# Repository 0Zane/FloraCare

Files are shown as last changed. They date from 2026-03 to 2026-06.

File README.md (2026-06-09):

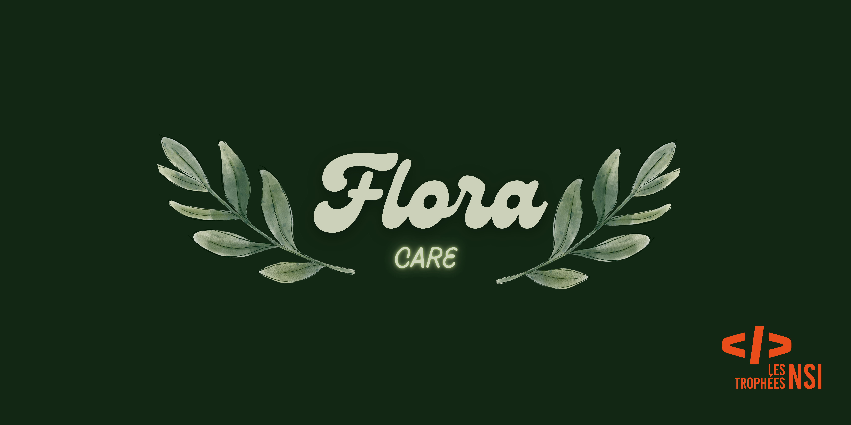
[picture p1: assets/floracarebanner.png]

# FloraCare

    

> Plant Tamagotchi — a connected device that monitors a plant's health using temperature, air humidity, soil moisture and light sensors. Built for the Trophées NSI 2026 (theme: Nature).

## 🎯 Goal

This project was created for the [Trophées NSI 2026](https://trophees-nsi.fr/) by @0Zane and @coderyansky. It offers a playful and educational experience: a digital companion that helps care for a plant by displaying real-time sensor data.

## 🏆 Awards

- **Regional Winner — Nature & Informatique**: FloraCare received the regional "Nature & Informatique" prize.
- **Nominated — Public Prize**: FloraCare was nominated for the Public Prize (see results).

See the official results: https://trophees-nsi.fr/resultats-2026

## 🧩 Hardware & Sensors

The project is based on a custom PCB driven by an **ESP32-S3**, chosen for native USB and enough power to run MicroPython.

| Component | Description | Interface / Protocol |
| :--- | :--- | :--- |
| **MCU** | ESP32-S3 Module | - |
| **PCB** | Custom design (Gerber files in `/hardware`) | - |
| **Display** | 1.9-inch 170x320 IPS color screen | **SPI** |
| **Temp / Humidity Sensor** | DHT22 | ADC |
| **Soil Moisture Sensor** | Analog soil moisture sensor | **ADC** |
| **Light Sensor** | BH1750 | **I2C** |
| **Power** | USB-C port | **5V DC -> 3.3V DC** |

> ⚡ The firmware runs on **MicroPython** and is intended to run continuously when powered via USB-C.

## 🚀 Quick Start

1. Flash MicroPython firmware to the ESP32-S3.
2. Copy all Python files to the microcontroller's flash.
3. Connect sensors to the pins defined in `main.py`.
4. Power via USB-C and observe readings on the display.

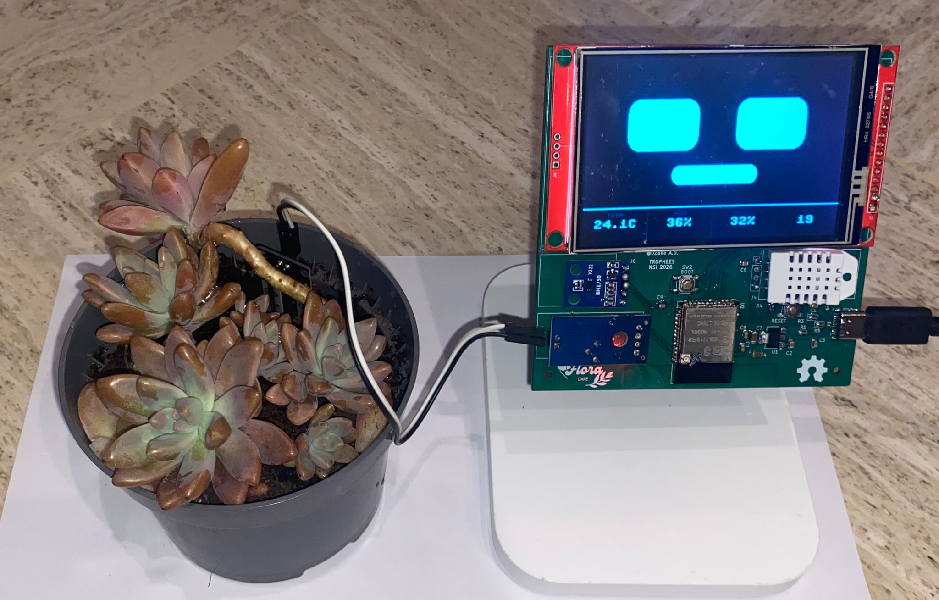
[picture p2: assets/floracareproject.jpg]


## 🌐 WiFi Web Interface

FloraCare creates a WiFi Access Point (AP) that serves a web interface to view plant data remotely.

### WiFi connection info

| Parameter | Value |
| :--- | :--- |
| **SSID** | `FloraCare` |
| **Password** | `pythonTNSI2026` |
| **IP Address** | `192.168.4.1` |
| **Protocol** | **HTTP** (port 80) |

### Accessing the web interface

1. Connect your device (phone, tablet, PC) to the `FloraCare` WiFi network.
2. Use the password `pythonTNSI2026`.
3. Open a browser and go to `http://192.168.4.1`.
4. The web page shows real-time sensor values (temperature, humidity, light, soil moisture).

> 💡 Tip: the web interface is available while the ESP32-S3 is powered via USB-C.

## 📁 Repository Structure

- `src/`: MicroPython code (main, libraries, config)
- `hardware/`: Gerber and PCB files (KiCad)
- `README.md`: project documentation and user guide
- `presentation.md`: project presentation
- `requirements.txt`: required libraries
- `LICENSE`: GPL v3

## 🤝 Contributing

This project is open source and open hardware. Contributions are welcome.
## 📝 License

This project is licensed under **GPL v3**. See the `LICENSE` file for details.

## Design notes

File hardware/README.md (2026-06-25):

# PCB FloraCare

## 📋 Description

This is the printed circuit board (PCB) for the FloraCare project, designed to control and monitor plant growing conditions.

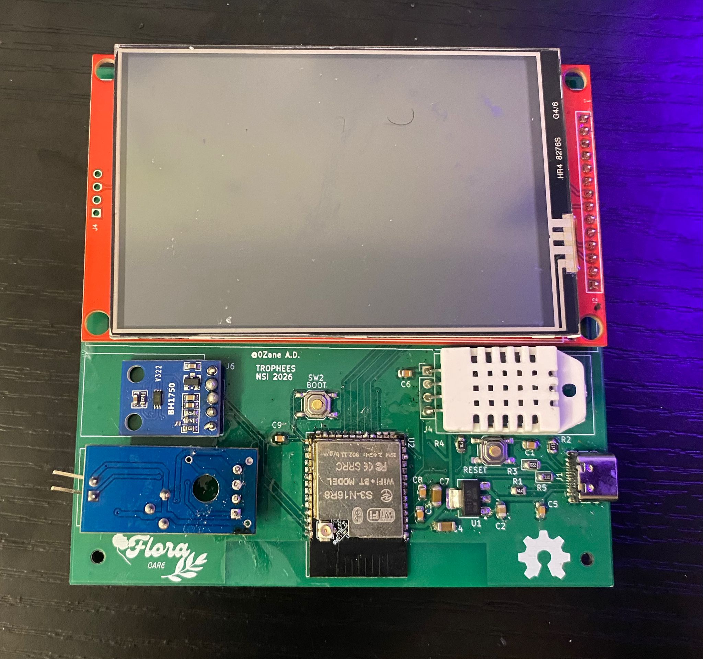
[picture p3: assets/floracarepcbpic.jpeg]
Floracare


## 🛠 Design

* **Design Tool**: KiCad
* **Design Files**:

  * `floracare.kicad_sch` - Electrical schematic
  * `floracare.kicad_pcb` - PCB layout
  * `floracare.kicad_pro` - KiCad project file

## 📐 PCB Preview

View the PCB rendering:

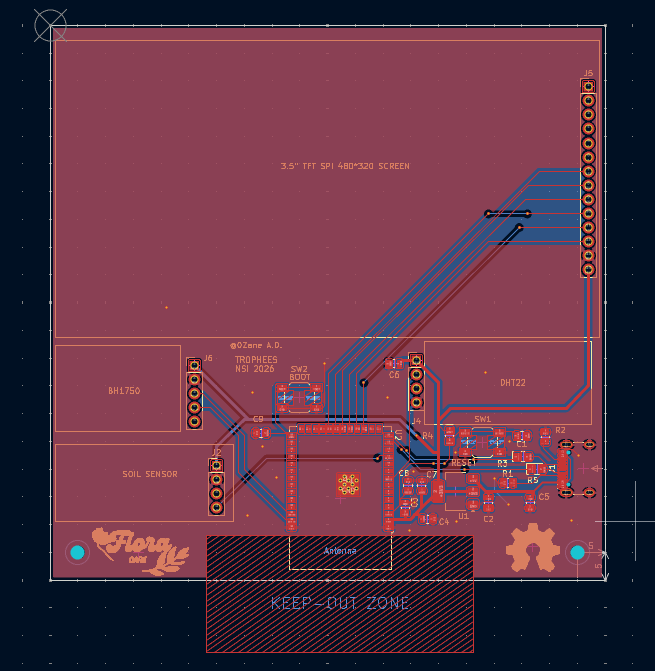
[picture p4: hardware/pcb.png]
PCB FloraCare


## 📄 Electrical Schematic

For detailed PCB documentation, see: [floracare.pdf](floracare.pdf)

## 🏭 Manufacturing

The PCB was ordered from **JLCPCB** for fabrication.
Assembly is done by hand by @0Zane.

* **Manufacturer**: JLCPCB
* **Export Format**: Gerber files + drill files

## 📦 Directory Structure

```text
hardware/
├── floracare.kicad_sch       # Electrical schematic
├── floracare.kicad_pcb       # PCB design
├── floracare.kicad_pro       # Project file
├── pcb.png                   # PCB preview
├── floracare.pdf             # Complete documentation
└── README.md                 # This file
```

## 🔧 Required Tools

To view or modify this PCB project, you will need:

* **KiCad** 9.0 (https://www.kicad.org)

---

For any questions regarding the PCB or its manufacturing process, please open a discussion in the GitHub repository's Discussions section.

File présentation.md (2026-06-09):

# 🌱 FloraCare — Project Presentation

## 1. Overall Project Overview

The project idea was born thanks to Zane, leveraging his knowledge of electronics and Python in connection with the proposed theme.

We asked ourselves the following question:  
**How can we help humans care for their plants in a playful and intuitive way?**

The objective of the *FloraCare* project is therefore to simplify understanding a plant's needs by giving it a form of "communication" with humans, through sensors and a clear interface.

---

## 2. Work Organization

### 👥 Team
- **Zane** — 1st year CS student, enthusiast of C++, Python, and electronics.
- **CoderyanskyK** — 1st year CS student, passionate about Python.

### 🛠️ Role Distribution

**Zane:**
- Python development  
- PCB design (circuit board)  
- Sensor function integration into the code  
- Wi-Fi setup and web interface via ESP  

**Coderyansky:**
- Python development  
- Sensor function integration into the code  
- Display programming (advanced graphical interface)  

### Time spent on the project:
Zane heard about the project in February and began looking for a teammate. After finding Coderyansky, we worked throughout March.

---

## 3. Project Stages

1. **Ideation and organization**
   - Team formation  
   - Reflection (~2h) on the concept and task distribution  

2. **Parallel development**
   - Zane: rapid PCB design (time constraint)  
   - CoderyanskyK: beginning screen interface development  

3. **Sensor selection (critical step)**
   - Compatibility with MicroPython  
   - Affordable cost  
   - Easy PCB integration  
   - Data relevance  

4. **Code structuring**
   - Organization for readability and performance  

5. **Advanced development**
   - Zane: Wi-Fi + web interface  
   - CoderyanskyK: screen finalization + sensors  

6. **Assembly**
   - PCB reception  
   - Soldering and hardware testing  

---

## 4. Validation and Operation

### ✅ Project Status
- Functional circuit board  
- Functional global code  

### 🧪 Testing Methods

- **Hardware tests:**
  - Use of a multimeter  
  - Verification of physical condition (temperature, circuit board robustness)

- **Software tests:**
  - Debug via console (Thonny IDE)  
  - Addition of `print` messages  

- **Data validation:**
  - Comparison with a thermometer  
  - Logical tests  
  - Real-world system usage  

### ⚠️ Challenges Encountered

- Sensor selection  
- Display programming in MicroPython  
- Setting up a Wi-Fi access point  
- Rapid PCB design (1 week)

---

## 5. Openings and Perspectives

### 🚀 Possible Improvements
- Addition of a finalized enclosure  
- Integration of more plant types  

### 🔍 Critical Analysis
The project addresses competition constraints with an original solution.  
The use of external resources (drivers, documentation) accelerated development.  
Artificial intelligence was used strategically for secondary tasks (HTML, descriptions).

### 🧠 Skills Developed
- Teamwork with GitHub  
- Rigor in electronics (no "it works roughly")  
- Application of Python skills acquired in CS in a real-world context  
- Understanding of HTTP protocol  

### 🤝 Inclusive Approach
The project aims to make plant care accessible to everyone, including beginners, through a simple and understandable interface.

---

## ⚙️ Deployment

⚠️ **Important:**  
Import **all files into flash memory** before execution (possible via ThonnyIDE).

---

## 📚 Sources

- https://docs.python.org/fr/3/howto/sockets.html  
- https://randomnerdtutorials.com/micropython-wi-fi-manager-esp32-esp8266/  
- https://requests.readthedocs.io/en/latest/  
- https://documentation.espressif.com/esp32-s3_datasheet_en.pdf
- https://github.com/lvgl-micropython/lvgl_micropython

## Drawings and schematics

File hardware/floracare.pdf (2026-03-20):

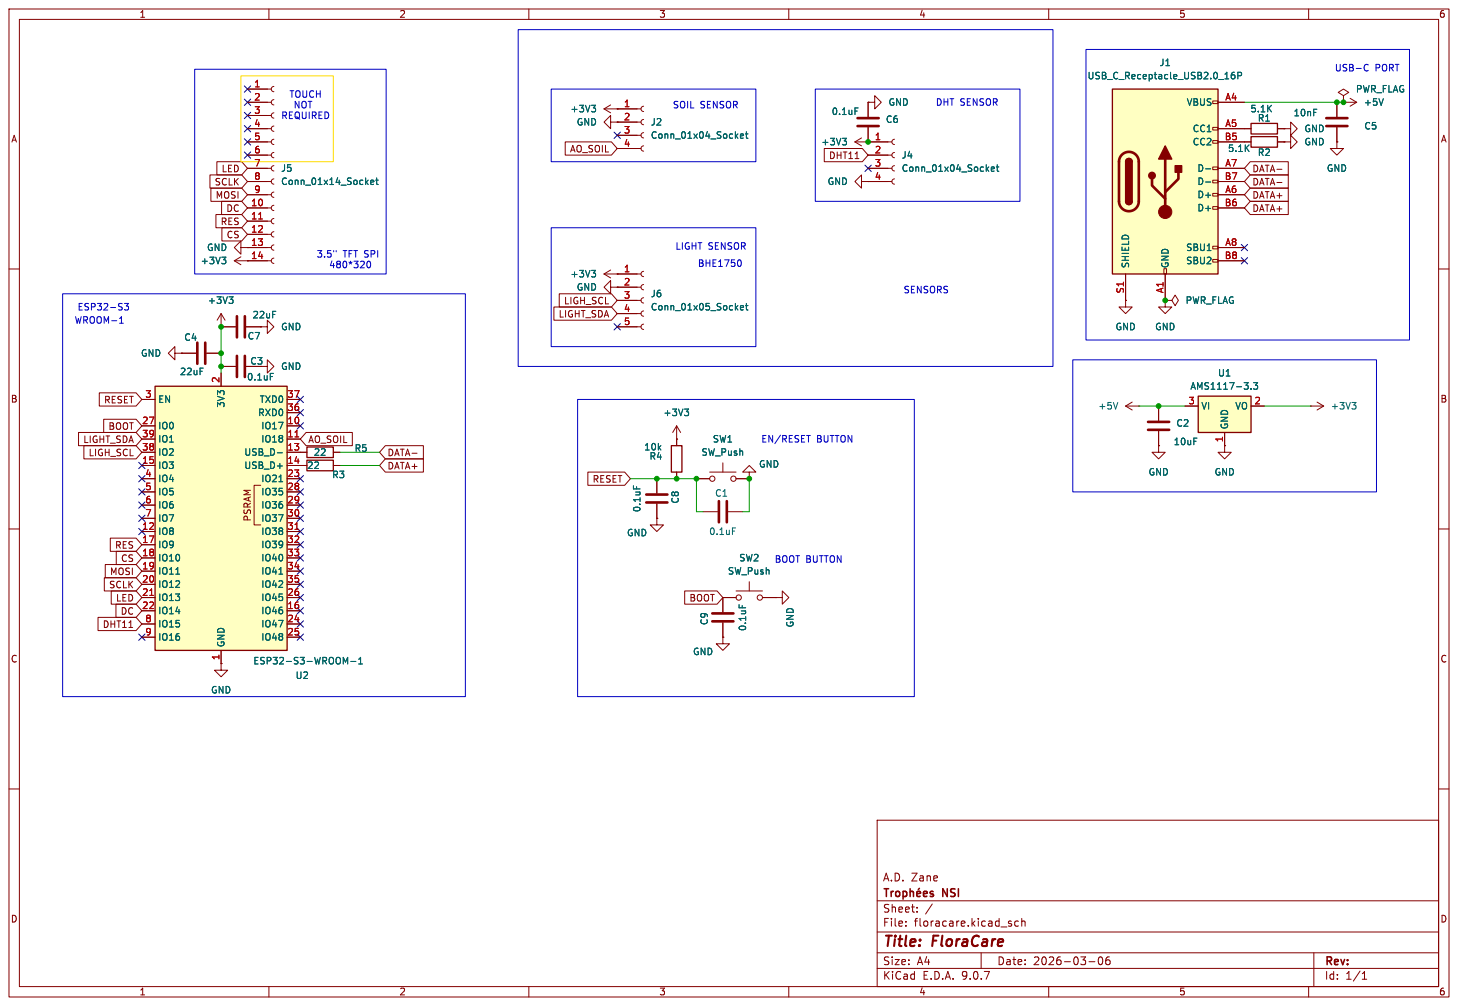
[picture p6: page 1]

+3V3 RES CS RES MOSI LED

1 VO 2 GND GND GND

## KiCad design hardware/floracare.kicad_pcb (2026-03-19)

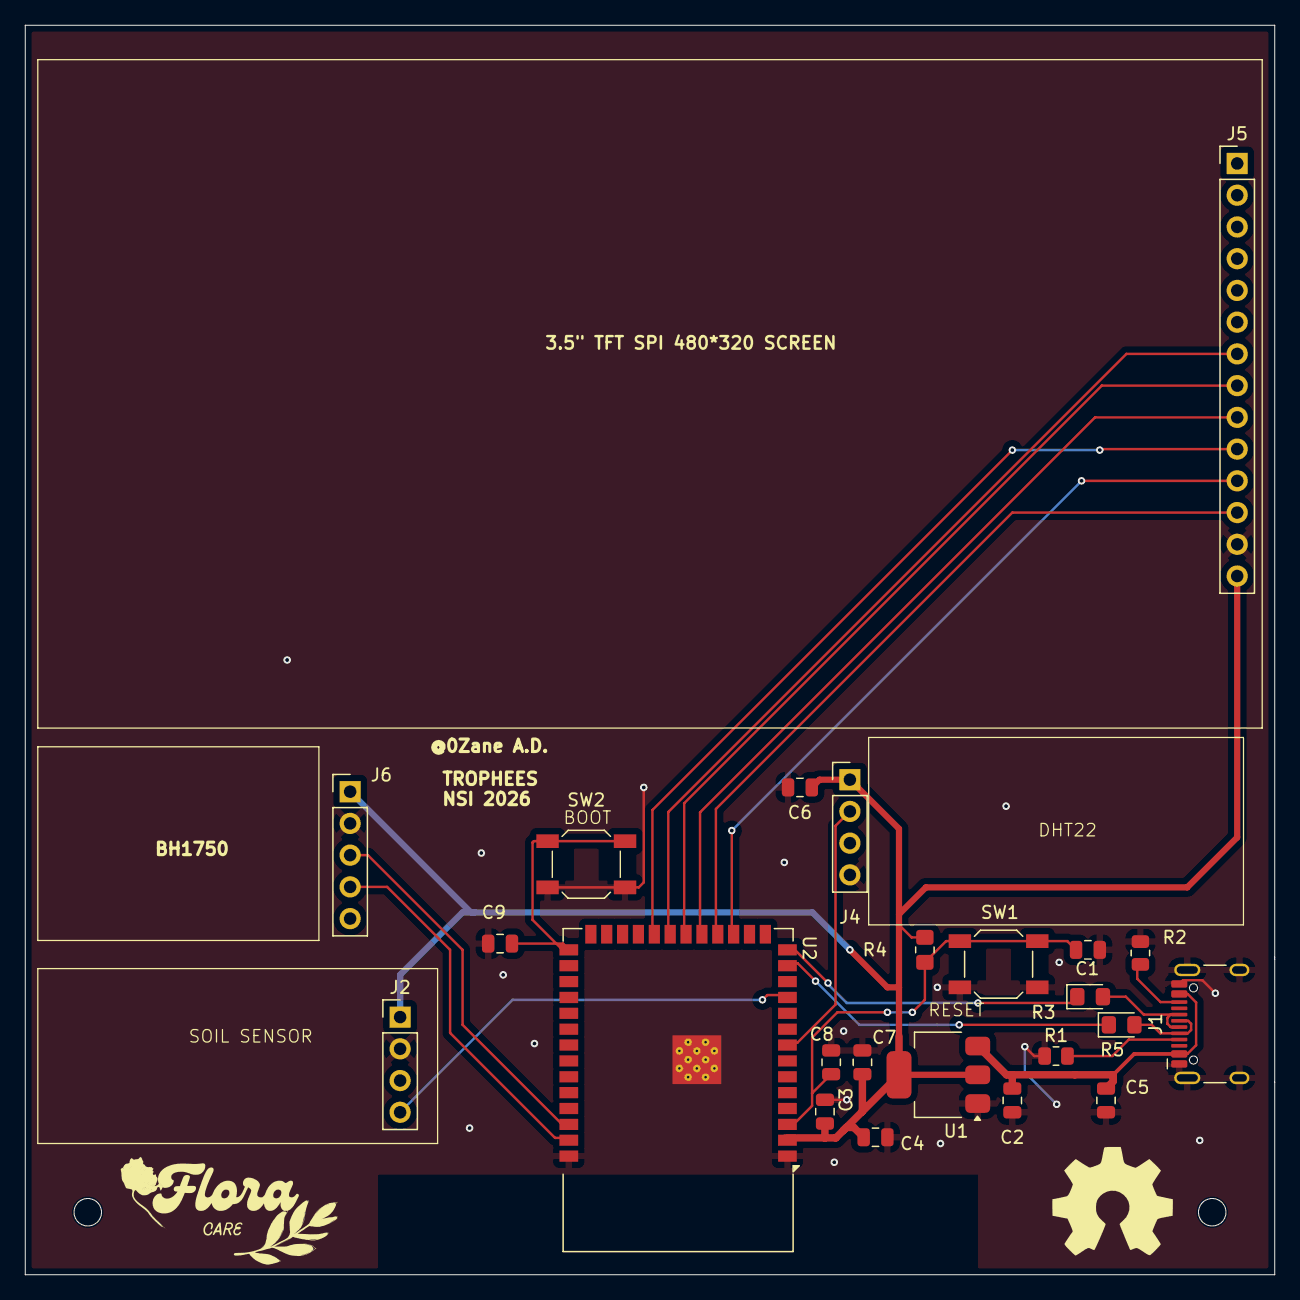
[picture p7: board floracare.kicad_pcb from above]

Board: 2 copper layers, 100.0 x 100.0 mm, 23 parts (0 on the bottom side), 21 nets.

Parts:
C1, C3, C6, C8, C9: 0.1uF; C_0805_2012Metric
C2: 10uF; C_0805_2012Metric
C4, C7: 22uF; C_0805_2012Metric
C5: 10nF; C_0805_2012Metric
J1: USB_C_Receptacle_USB2.0_16P; USB_C_Receptacle_HCTL_HC-TYPE-C-16P-01A
J2, J4: Conn_01x04_Socket; PinHeader_1x04_P2.54mm_Vertical
J5: Conn_01x14_Socket; PinHeader_1x14_P2.54mm_Vertical
J6: Conn_01x05_Socket; PinHeader_1x05_P2.54mm_Vertical
R1, R2: 5.1K; R_0805_2012Metric
R3, R5: 22; LED_0805_2012Metric_Pad1.15x1.40mm_HandSolder
R4: 10k; R_0805_2012Metric_Pad1.20x1.40mm_HandSolder
SW1, SW2: SW_Push; SW_SPST_SKQG_WithStem
U1: AMS1117-3.3; SOT-223-3_TabPin2
U2: ESP32-S3-WROOM-1

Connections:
+3V3: C3.2, C4.1, C6.1, C7.1, J2.1, J4.1, J5.14, J6.1, R4.2, U1.2 (VO), U2.2 (3V3)
+5V: C2.2, C5.1, J1.A4 (VBUS), J1.A9 (VBUS), J1.B4 (VBUS), J1.B9 (VBUS), U1.3 (VI)
AO_SOIL: J2.4, U2.11 (IO18)
BOOT: C9.2, SW2.1, U2.27 (IO0)
CS: J5.12, U2.18 (IO10)
DATA+: J1.A6 (D+), J1.B6 (D+), R3.2
DATA-: J1.A7 (D-), J1.B7 (D-), R5.2
DC: J5.10, U2.22 (IO14)
DHT11: J4.2, U2.8 (IO15)
GND: C1.2, C2.1, C3.1, C4.2, C5.2, C6.2, C7.2, C8.2, C9.1, J1.A1 (GND), J1.A12 (GND), J1.B1 (GND), J1.B12 (GND), J1.S1 (SHIELD), J2.2, J4.4, J5.13, J6.2, R1.1, R2.2, SW1.2, SW2.2, U1.1 (GND), U2.1 (GND), U2.40 (GND), U2.41 (GND)
LED: J5.7, U2.21 (IO13)
LIGHT_SDA: J6.4, U2.39 (IO1)
LIGH_SCL: J6.3, U2.38 (IO2)
MOSI: J5.9, U2.19 (IO11)
unnamed: J1.A5 (CC1), R1.2
unnamed: J1.B5 (CC2), R2.1
unnamed: R3.1, U2.14 (USB_D+)
unnamed: R5.1, U2.13 (USB_D-)
RES: J5.11, U2.17 (IO9)
RESET: C1.1, C8.1, R4.1, SW1.1, U2.3 (EN)
SCLK: J5.8, U2.20 (IO12)

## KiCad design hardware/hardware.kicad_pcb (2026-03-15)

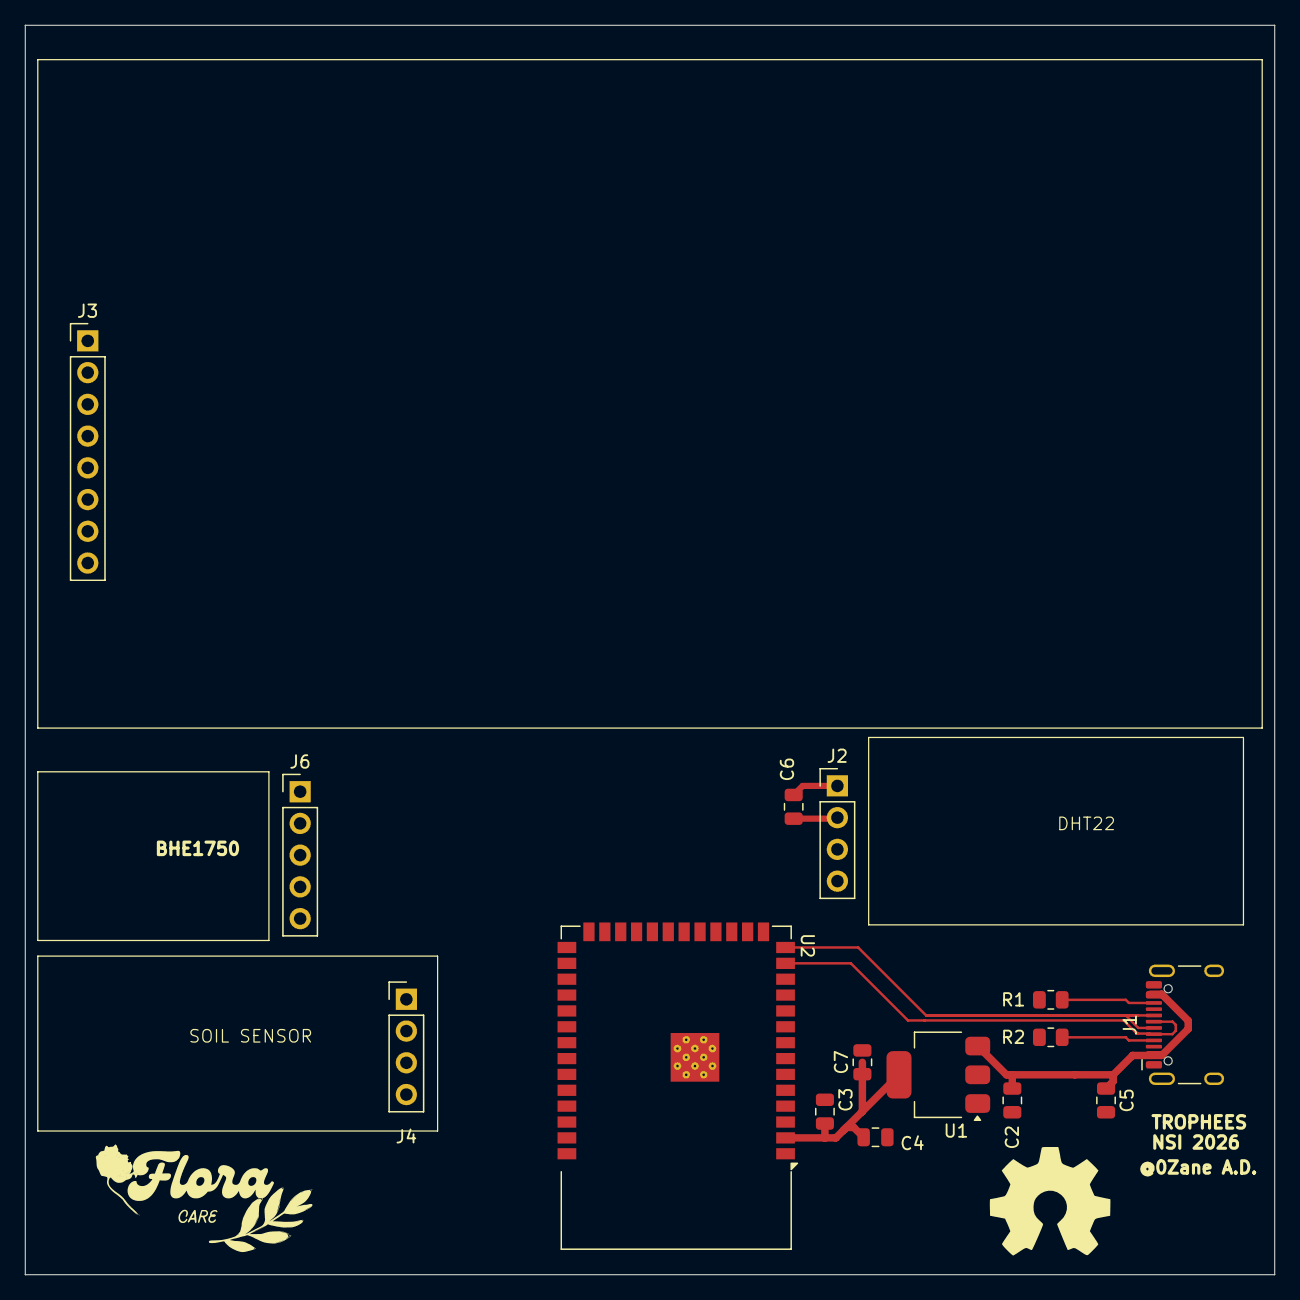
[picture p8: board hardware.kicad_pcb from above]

Board: 2 copper layers, 100.0 x 100.0 mm, 15 parts (0 on the bottom side), 14 nets.

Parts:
C2: 10uF; C_0805_2012Metric
C3, C6: 0.1uF; C_0805_2012Metric
C4, C7: 22uF; C_0805_2012Metric
C5: 10nF; C_0805_2012Metric
J1: USB_C_Receptacle_USB2.0_14P; USB_C_Receptacle_HCTL_HC-TYPE-C-16P-01A
J2, J4: Conn_01x04_Socket; PinHeader_1x04_P2.54mm_Vertical
J3: Conn_01x08_Socket; PinHeader_1x08_P2.54mm_Vertical
J6: Conn_01x05_Socket; PinHeader_1x05_P2.54mm_Vertical
R1, R2: 5.1K; R_0805_2012Metric
U1: AMS1117-3.3; SOT-223-3_TabPin2
U2: ESP32-S3-WROOM-1

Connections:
+3V3: C3.2, C4.1, C6.1, C7.1, J2.1, J3.7, J4.1, J6.1, U1.2 (VO), U2.2 (3V3)
+5V: C2.2, C5.1, J1.A4 (VBUS), J1.A9 (VBUS), J1.B4 (VBUS), J1.B9 (VBUS), U1.3 (VI)
AO_SOIL: J2.4, U2.11 (IO18)
CS: J3.2, U2.18 (IO10)
DATA+: J1.A6 (D+), J1.B6 (D+), U2.14 (USB_D+)
DATA-: J1.A7 (D-), J1.B7 (D-), U2.13 (USB_D-)
DC: J3.3, U2.22 (IO14)
DHT11: J4.2, U2.9 (IO16)
GND: C2.1, C3.1, C4.2, C5.2, C6.2, C7.2, J1.A1 (GND), J1.A12 (GND), J1.B1 (GND), J1.B12 (GND), J1.S1 (SHIELD), J2.2, J3.8, J4.4, J6.2, R1.2, R2.2, U1.1 (GND), U2.1 (GND), U2.40 (GND), U2.41 (GND)
MOSI: J3.5, U2.19 (IO11)
unnamed: J1.A5 (CC1), R2.1
unnamed: J1.B5 (CC2), R1.1
RES: J3.4, U2.21 (IO13)
SCLK: J3.6, U2.20 (IO12)

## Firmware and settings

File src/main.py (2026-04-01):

import dht
import time
from machine import Pin, ADC, I2C
import socket
import network
from webpage import webpage
import ujson
from statehandler import plantstate
from drivers.display.robot_face import Display as FaceDisplay, Face
from drivers.display.anims.idle import IdleAnim
from drivers.display.anims.angry import AngryAnim

# --- Sensor pins ---
SOIL_PIN  = 18
DHT_PIN   = 15
LIGHT_SCL = 2
LIGHT_SDA = 1

# --- Screen pins ---
RES  = 9
CS   = 10
MOSI = 11
SCLK = 12
LED  = 13
DC   = 14


# --- Hardware addresses ---
BH1750_ADDR       = 0x23
BH1750_CONT_H_RES = 0x10

# --- Wi-Fi access point ---
SSID          = "FloraCare"
WIFIPASSWORD  = "pythonTNSI2026"
MAX_USER      = 4
MAX_PACKETSIZE = 1024
APWIFI = True  # set to False when the AP is disabled at runtime

# --- Plant models ---
orchidee = {"name": "ORCHIDEE", "humid": 65, "temp": 22, "moisture": 55, "light": 45}
cactus   = {"name": "CACTUS",   "humid": 20, "temp": 28, "moisture": 20, "light": 85}
monstera = {"name": "MONSTERA", "humid": 58, "temp": 24, "moisture": 60, "light": 40}
jacinthe = {"name": "JACINTHE", "humid": 50, "temp": 14, "moisture": 50, "light": 70}
graptosedum = {"name": "GRAPTOSEDUM", "humid": 40, "temp":22, "moisture": 40, "light": 50 }

# Dictionary mapping POST plant names to their model
PLANT_MODELS = {
    "orchidee": orchidee,
    "cactus":   cactus,
    "monstera": monstera,
    "jacinthe": jacinthe,
    "graptosedum": graptosedum
}

# --- Light average state ---
period  = 0
lum_sum = 0
lightstate = 0
# --- Plant target thresholds (updated when a plant is selected via the web UI) ---
norm_air_temp = 22
norm_air_hum  = 40
norm_moisture = 50
norm_light    = 1

# --- Sensor initialisation ---
capteur = dht.DHT22(Pin(DHT_PIN))
adc     = ADC(Pin(SOIL_PIN))
i2c     = I2C(0, sda=Pin(LIGHT_SDA), scl=Pin(LIGHT_SCL), freq=400000)
try:
    i2c.writeto(BH1750_ADDR, bytes([BH1750_CONT_H_RES]))
except:
    print("Light sensor not found — skipping init")


# --- Sensor read functions ---

def read_light():
    try:
        data = i2c.readfrom(BH1750_ADDR, 2)
        return (data[0] << 8 | data[1]) / 1.2
    except:
        return -1


def read_soil():
    try:
        adc.atten(ADC.ATTN_11DB)
        raw = adc.read_u16()
        moisture_pct = max(0, min(100, 100 - (raw * 100 // 65535)))
        return raw, moisture_pct
    except:
        return -1, -1


def read_temp():
    try:
        capteur.measure()
        temp = capteur.temperature()
        humi = capteur.humidity()
        return temp, humi
    except:
        return -1, -1


# --- Wi-Fi access point ---

def launch_ap():
    try:
        sta = network.WLAN(network.AP_IF)
        sta.active(True)
        sta.config(essid=SSID, authmode=network.AUTH_WPA_WPA2_PSK, password=WIFIPASSWORD)
        print("Network config:", sta.ifconfig())
    except:
        print("Failed to launch AP")


# --- Boot sequence ---

launch_ap()

face = Face(FaceDisplay())
face.set_anim(IdleAnim())

try:
    socketFloraCare = socket.socket(socket.AF_INET, socket.SOCK_STREAM)
    socketFloraCare.setsockopt(socket.SOL_SOCKET, socket.SO_REUSEADDR, 1)
    socketFloraCare.bind(('', 80))
    socketFloraCare.listen(MAX_USER)
    socketFloraCare.setblocking(False)
    print("Server listening on port 80")
except Exception as e:
    print(f"Error creating socket: {e}")
    socketFloraCare = None

# --- Main loop ---

_sensor_at = time.ticks_ms()
_temp = _humi = _soil_pct = _lux = -1

while True:
    face.update()

    if socketFloraCare and APWIFI:
        try:
            conn, addr = socketFloraCare.accept()
            conn.settimeout(2.0)
            print("Connection from", addr)
            request    = conn.recv(MAX_PACKETSIZE).decode('utf-8')
            first_line = request.split('\r\n')[0]
            print(request)

            if "POST /save" in first_line:
                try:
                    parts = request.split('\r\n\r\n')
                    if len(parts) > 1:
                        data       = ujson.loads(parts[1])
                        plant_name = data.get("plant")
                        selected   = PLANT_MODELS.get(plant_name)

                        if selected:
                            norm_air_temp = selected["temp"]
                            norm_air_hum  = selected["humid"]
                            norm_moisture = selected["moisture"]
                            norm_light    = selected["light"]
                            print(f"Succès : {plant_name} configurée.")
                            print(f"Objectif : Temp {norm_air_temp}°C, Hum {norm_air_hum}%")
                        else:
                            print(f"Erreur : La plante '{plant_name}' n'existe pas dans la base de données FloraCare")

                        conn.send("HTTP/1.1 200 OK\r\nContent-Type: application/json\r\n\r\n")
                except Exception as e:
                    print("POST /save error:", e)

            elif "POST /wifi_off" in first_line:
                conn.send("HTTP/1.1 200 OK\r\n\r\nDisabling Wi-Fi...")
                conn.close()
                time.sleep(1)
                network.WLAN(network.AP_IF).active(False)
                APWIFI = False
                print("Wi-Fi AP disabled")

            else:
                response = webpage()
                conn.send("HTTP/1.0 200 OK\r\nContent-type: text/html\r\n\r\n")
                conn.send(response)
                conn.close()

        except:
            pass  # no incoming connection — non-blocking accept raises here

    # Read sensors every 2 s without blocking the animation loop
    if time.ticks_diff(time.ticks_ms(), _sensor_at) >= 0:
        _sensor_at = time.ticks_ms() + 2000

        try:
            _temp, _humi = read_temp()
            # DHT22 and display DC share GPIO 15 — restore pin direction after DHT use
            face.lcd.restore_dc()
            _raw, _soil_pct = read_soil()
            _lux            = read_light()

            tempstate, humstate, moiststate = plantstate(
                _temp, norm_air_temp, _humi, norm_air_hum, _soil_pct, norm_moisture
            )

            if period < 1000:
                period  += 1
                lum_sum += _lux
            elif period >= 1000:
                period  = 0
                avg_lum = lum_sum // 1000
                lum_sum = 0
                if avg_lum + 10 < norm_light:
                    lightstate = -1
                    print("Votre plante est en manque de lumière depuis quelques temps.")

            if any(s != 0 for s in (tempstate, humstate, moiststate, lightstate)):
                if not isinstance(face._anim, AngryAnim):
                    face.set_anim(AngryAnim())
            else:
                if not isinstance(face._anim, IdleAnim):
                    face.set_anim(IdleAnim())

            if tempstate == 1:
                print("Votre plante a trop chaud.")
            elif tempstate == -1:
                print("Votre plante a froid.")

            if moiststate == 1:
                print("Votre plante est trop submergée.")
            elif moiststate == -1:
                print("Votre plante est en sécheresse, veuillez arroser la plante.")

            if humstate == 1:
                print("L'air est trop humide pour votre plante.")
            elif humstate == -1:
                print("L'air est trop sec pour votre plante.")

            face.set_sensors(_temp, _humi, _soil_pct, _lux,
                             [tempstate, humstate, moiststate, lightstate])

        except Exception as e:
            print(f"Sensor error: {e}")
            face.set_sensors(_temp, _humi, _soil_pct, _lux)
        

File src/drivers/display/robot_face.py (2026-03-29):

"""Animated robot face on ILI9488 480x320 SPI display (ESP32-S3).

Raw SPI driver + two blinking eyes (no pupils).
Standard MicroPython only — no LVGL, no external libraries.
"""

import machine
import time
import math
import framebuf  # MicroPython built-in
from drivers.display.anims.idle import IdleAnim

# --- Pins ---
_RES  = 9
_CS   = 10
_MOSI = 11
_SCLK = 12
_LED  = 13
_DC   = 14
_MISO = 14

# --- Screen ---
W, H = 480, 320

# --- RGB666 colors (3 bytes per pixel, lower 2 bits of each byte ignored) ---
BG   = b'\x04\x08\x18'  # ~#040818 deep black-navy
BLUE = b'\x00\xFC\xFC'  # max brightness cyan
DIM  = b'\x00\x60\x70'  # dimmed cyan for labels (~38% brightness)
RED  = b'\xFC\x00\x00'  # alert red for out-of-range values

# --- Sensor bar layout (bottom of screen) ---
_SEP_Y  = 260          # separator line y (mouth ends at 215+38=253)
_BAR_Y  = 262          # bar background start
_LBL_Y  = 270          # label row y  (scale=1 → 8px high)
_VAL_Y  = 282          # value row y  (scale=2 → 16px high, ends at 298)
_COL_CX = (60, 180, 300, 420)   # column centers
_COL_XS = (0, 120, 240, 360)    # column left edges
_COL_W  = 120


class Display:
    """ILI9488 raw SPI driver, RGB666 mode, 480x320 landscape."""

    def __init__(self):
        self.spi = machine.SoftSPI(
            baudrate=40_000_000, polarity=0, phase=0,
            sck=machine.Pin(_SCLK), mosi=machine.Pin(_MOSI),
            miso=machine.Pin(_MISO),
        )
        self.cs = machine.Pin(_CS, machine.Pin.OUT, value=1)
        self.dc = machine.Pin(_DC, machine.Pin.OUT, value=1)
        self.rst = machine.Pin(_RES, machine.Pin.OUT, value=1)
        self.led = machine.Pin(_LED, machine.Pin.OUT, value=0)
        self._init_hw()
        self.led.value(1)

    def _cmd(self, c, d=None):
        self.cs.value(0)
        self.dc.value(0)
        self.spi.write(bytes([c]))
        if d is not None:
            self.dc.value(1)
            self.spi.write(d if isinstance(d, (bytes, bytearray)) else bytes(d))
        self.cs.value(1)

    def _init_hw(self):
        self.rst.value(0)
        time.sleep_ms(20)
        self.rst.value(1)
        time.sleep_ms(120)
        self._cmd(0x01)  # Software reset
        time.sleep_ms(120)
        self._cmd(0x11)  # Sleep out
        time.sleep_ms(120)

        # Gamma
        self._cmd(0xE0, b'\x00\x03\x09\x08\x16\x0A\x3F\x78'
                        b'\x4C\x09\x0A\x08\x16\x1A\x0F')
        self._cmd(0xE1, b'\x00\x16\x19\x03\x0F\x05\x32\x45'
                        b'\x46\x04\x0E\x0D\x35\x37\x0F')
        # Power
        self._cmd(0xC0, b'\x17\x15')
        self._cmd(0xC1, b'\x41')
        self._cmd(0xC5, b'\x00\x12\x80')
        # Display
        self._cmd(0x36, b'\x28')  # MADCTL: landscape rotated 180 + BGR (MY=0, MX=0, MV=1, BGR=1)
        self._cmd(0x3A, b'\x66')  # 18-bit RGB666
        self._cmd(0xB0, b'\x00')  # Interface mode control
        self._cmd(0xB1, b'\xA0')  # Frame rate 60 Hz
        self._cmd(0xB4, b'\x02')  # Display inversion
        self._cmd(0xB6, b'\x02\x02')  # Display function control
        self._cmd(0xE9, b'\x00')  # Set image function
        self._cmd(0xF7, b'\xA9\x51\x2C\x82')  # Adjust control 3
        self._cmd(0x29)  # Display ON
        time.sleep_ms(50)

    def window(self, x, y, w, h):
        """Set the drawing window (CASET + RASET)."""
        xe, ye = x + w - 1, y + h - 1
        self._cmd(0x2A, bytes([x >> 8, x & 0xFF, xe >> 8, xe & 0xFF]))
        self._cmd(0x2B, bytes([y >> 8, y & 0xFF, ye >> 8, ye & 0xFF]))

    def start(self):
        """Begin RAMWR and hold CS low for pixel streaming."""
        self.cs.value(0)
        self.dc.value(0)
        self.spi.write(b'\x2C')
        self.dc.value(1)

    def stop(self):
        self.cs.value(1)

    def restore_dc(self):
        """Re-assert DC pin as output. Call after any code that may have disturbed GPIO."""
        self.dc = machine.Pin(_DC, machine.Pin.OUT, value=1)

    def fill(self, x, y, w, h, color):
        """Fill a rectangle with a solid RGB666 color."""
        self.window(x, y, w, h)
        row = color * w
        self.start()
        for _ in range(h):
            self.spi.write(row)
        self.stop()


class StatusBar:
    """Sensor data strip at the bottom of the screen."""

    _LABELS = ("TEMP", "HUM", "SOIL", "LUX")

    def __init__(self, lcd):
        self.lcd = lcd
        self._strs = [""] * 4
        self._states = [0] * 4  # 0 = normal, != 0 = out of range

    def draw_static(self):
        """Draw separator line, background and static labels. Call after full screen fill."""
        lcd = self.lcd
        lcd.fill(0, _SEP_Y, W, 2, BLUE)                 # neon separator
        lcd.fill(0, _BAR_Y, W, H - _BAR_Y, BG)          # bar background
        # Subtle column dividers
        for sx in (120, 240, 360):
            lcd.fill(sx, _SEP_Y + 2, 1, H - _SEP_Y - 2, DIM)
        # Labels
        for lbl, cx in zip(self._LABELS, _COL_CX):
            lx = cx - len(lbl) * 4   # scale=1: 8px/char, center
            self._draw_text(lx, _LBL_Y, lbl, scale=1, color=DIM)
        self._strs = [""] * 4        # force value redraw on next update()
        self._states = [0] * 4

    def _draw_text(self, x, y, text, scale=2, color=BLUE):
        n = len(text)
        if n == 0:
            return
        w8     = n * 8
        stride = (w8 + 7) // 8
        mono   = bytearray(stride * 8)
        fb     = framebuf.FrameBuffer(mono, w8, 8, framebuf.MONO_HMSB)
        fb.fill(0)
        fb.text(text, 0, 0, 1)
        sw      = w8 * scale
        row_buf = bytearray(sw * 3)
        mv      = memoryview(row_buf)
        lcd     = self.lcd
        spi     = lcd.spi
        lcd.window(x, y, sw, 8 * scale)
        lcd.start()
        for sy in range(8):
            off = 0
            for sx in range(w8):
                bit = (mono[sy * stride + sx // 8] >> (sx % 8)) & 1
                px  = color if bit else BG
                for _ in range(scale):
                    row_buf[off:off + 3] = px
                    off += 3
            for _ in range(scale):
                spi.write(mv)
        lcd.stop()
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

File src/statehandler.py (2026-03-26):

def plantstate(planttemp,temptarget, planthum, humtarget, plantmoist,moisttarget):


    #Defining plant tolerance to avoid too strict analysis
    TEMP_TOLERANCE = 6 
    HUM_TOLERANCE = 15
    MOIST_TOLERANCE = 10

#Defining plant state  :
# 
# -1 is not enough
# 0 is perfect
# 1 is too much
    temp_state = 0
    hum_state = 0
    moist_state = 0


    if planttemp + TEMP_TOLERANCE  < temptarget:
        temp_state = -1
    elif planttemp - TEMP_TOLERANCE  > temptarget:
        temp_state = 1

    if planthum + HUM_TOLERANCE < humtarget:
        hum_state = -1
    elif planthum - HUM_TOLERANCE  > humtarget:
        hum_state = 1

    if plantmoist + MOIST_TOLERANCE < moisttarget:
        moist_state = -1
    elif plantmoist  - MOIST_TOLERANCE > moisttarget:
        moist_state = 1


    


    #result will be in this form (tempstate, humstate, moiststate)

    return (temp_state, hum_state, moist_state)

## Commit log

2026-03-06 Initial led blink setup for esp32 s3
    This is the first step of the project to understand micropython.
    This branche will only be merged to the maun branch when it will contain the real firmware code.
2026-03-06 Adding temp feature
    Adding temperature reading with DHT11 using dht library , and ON LED
2026-03-07 Adding hardware directory for PCB
    [hardware.kicad_pcb, hardware.kicad_sch]
2026-03-08 Adding usbc port
    [hardware.kicad_sch]
2026-03-11 Adding SPI pin socket
    [hardware.kicad_sch]
2026-03-11 [ERC GOOD] , correcting tag name MOSI & SCLk, Adding tags to ESP-32-S3
    [hardware.kicad_sch]
2026-03-11 Making PCB + screen route + switching CS and DC pins
    [hardware.kicad_pcb, hardware.kicad_sch]
2026-03-12 Adding AMS117 Voltage divider (NO CAPACITOR)
    [hardware.kicad_sch]
2026-03-12 Adding usbc routes [ERC NOT STABLE]
    [hardware.kicad_pcb]
2026-03-12 Adding DHT sensor pins
    [hardware.kicad_pcb, hardware.kicad_sch]
2026-03-13 Add DHT22 sensor to README specifications
2026-03-14 Adding soil sensor pins
    [hardware.kicad_sch]
2026-03-14 [ERC VERIFIED] Adding soil sensor pin
    [hardware.kicad_sch]
2026-03-14 Adding Soil sensor on PCB
    [hardware.kicad_pcb]
2026-03-14 feat(sensor): add soil moisture reader on GPIO 18
    - Read analog soil moisture via ADC on GPIO 18
    - read_soil() returns raw u16 and moisture percentage (0-100%)
    - ATTN_11DB for 0-3.3V range; script runs in loop with 2s interval
    Made-with: Cursor
2026-03-14 Update Footprint property for connectors in schematic
    [hardware.kicad_sch]
2026-03-14 feat(display): show DHT11 and soil sensors on ST7789
    - Add display_sensor UI with cards, bars, incremental updates
    - Add 170x320 rotation table with xstart/ystart in driver
    - Clamp _set_window to valid range to fix edge corruption
    - main.py entry point runs display_sensor
    [main.py]
2026-03-15 Adding Light sensor pins on schematic
    [hardware.kicad_sch]
2026-03-15 Adding all capacitors
    [hardware.kicad_sch]
2026-03-15 Making first version of the PCB [NOT ROUTED ]
    [hardware.kicad_pcb, hardware.kicad_sch]
2026-03-15 Update README with sensor details and project description
2026-03-15 Removing message
    [hardware.kicad_sch]
2026-03-15 Placing silkscreen in better zones to preapare mounting holes
    [hardware.kicad_pcb]
2026-03-15 Putting ground over the back of the PCB
    [hardware.kicad_pcb]
2026-03-15 Revert "Merge branch 'feature/display-output' into main"
    This reverts commit b133c3eb0e3cd1f3bc46de7860bfc4a558904355, reversing
    changes made to 9a763ac953a70affe540ec869e4ab95926b2e80e.
    [main.py]
2026-03-15 Remaking hardware directory
    [floracarepcb.kicad_pcb, floracareschematic.kicad_sch]
2026-03-15 Repairing hardware repository [STABLE]
    [floracare.kicad_pcb, floracare.kicad_sch]
2026-03-15 Update global pcb
    [floracare.kicad_pcb, floracare.kicad_sch]
2026-03-16 Fixing size hole problem and mass plan [ ERC 9 ERRORS ]
    [floracare.kicad_pcb]
2026-03-16 Adding vias
    [floracare.kicad_pcb]
2026-03-17 Adding EN and BOOT buttons
    [floracare.kicad_sch]
2026-03-17 Fixing PCB + adding BOOT and RESET BUTTONS [DRC NOT STABLE]
    [floracare.kicad_pcb]
2026-03-17 Updating general Project
    [floracare.kicad_pcb, floracare.kicad_sch]
2026-03-18 Adding 2 mounting holes
    [floracare.kicad_pcb]
2026-03-18 Replacing usb slot
    [floracare.kicad_pcb, floracare.kicad_sch]
2026-03-18 feat: add ILI9488 display driver
    Based on Kevin G. Schlosser's implementation (Copyright 2024-2025).
    Includes LVGL-compatible wrapper, initialization sequence, and raw SPI driver
    without external framework dependencies. Also adds lcd_bus type stubs.
2026-03-18 Rounting UCBC 8 pin
    [floracare.kicad_pcb]
2026-03-19 Finishing PCB , [USBC NOT STABLE WITH DRC]
    [floracare.kicad_pcb, floracare.kicad_sch]
2026-03-19 Finishing USB-C Routing & PCB [DRC STABLE]
    [floracare.kicad_pcb, floracare.kicad_sch]
2026-03-19 Repacing silk [Warnings Fixed on DRC except1 ]
    [floracare.kicad_pcb]
2026-03-19 Fixing ESP32 -S3 WRROM1 MODULE Warning [DRC 100% STABLE]
    [floracare.kicad_pcb]
2026-03-19 Adding mounting holes
    [floracare.kicad_pcb]
2026-03-19 Correcting details
    [floracare.kicad_pcb]
2026-03-19 Define sensor and screen pin constants
    Added constants for sensor and screen pins, and improved comments.
2026-03-20 feat: add BH1750 light sensor and switch DHT11 to DHT22
2026-03-20 Uploading PCB images
2026-03-21 Correcting bug and handling error
    [main.py]
2026-03-21 Correcting spelling mistake on launch function
    [main.py]
2026-03-21 Adding server hosted by ESP Device
2026-03-22 feat: add animated robot face driver for ILI9488 480x320 display
2026-03-24 Remove 3D printed case details from README
    Removed the 3D printed case information from the README.
2026-03-24 Correcting pin during PCB test
    [main.py]
2026-03-25 Correcting pin
2026-03-25 Correcting variable definition bug
    [main.py]
2026-03-26 Implement feedback messages for plant care states
    Added print statements for plant care conditions based on temperature, moisture, humidity, and light levels.
2026-03-26 remove(display): drop LVGL-based ILI9488 driver and init module
    Replaced by a custom MicroPython SPI driver that requires no LVGL
    or lcd_bus dependencies.
2026-03-26 refactor(display): redesign Face with StatusBar, batch SPI, and no pupils
    - Remove drifting pupil animation; eyes are now solid rounded rectangles
    - Add StatusBar class: draws TEMP/HUM/SOIL/LUX strip below a neon separator
    - Batch eye rows in groups of 8 to reduce SPI transaction overhead
    - Double SPI baudrate to 40 MHz and fix MADCTL for correct landscape orientation
    - Rate-limit blink animation with _BSTEP_MS instead of blocking sleep_ms
    - Add restore_dc() on Display to reclaim GPIO 15 after DHT22 use
    - Add mouth rendered as a filled rounded rectangle
    [robot_face.py]
2026-03-26 refactor(main): integrate Face, non-blocking sensor loop, cleanup
    - Instantiate Face at boot and call face.update() on every loop iteration
    - Schedule sensor reads every 2 s with ticks_ms instead of blocking sleep
    - Call face.lcd.restore_dc() after each DHT22 read to reclaim GPIO 15
    - Push sensor readings to face.set_sensors() for StatusBar display
    - Fix light average accumulation (reset lum_sum on period rollover)
    - Clean up comments, align constants, translate log messages to English
    [main.py]
2026-03-26 fix(main): add 2s timeout on socket recv to prevent hang on stalled connections
    [main.py]
2026-03-26 fix(main): restore plant state debug prints, screen pin constants, and f-strings
    [main.py]
2026-03-26 feat(anims): add AngryAnim — red eyes with diagonal brow cutoff and blink
2026-03-26 refactor(face): replace inline blink logic with pluggable animation system
    [robot_face.py]
2026-03-27 Adding picture of pcb physical
2026-03-28 fix(display): correct DC and MISO pin numbers to GPIO 14
    _DC was set to 15 (wrong), now matches the hardware schematic (GPIO 14).
    MISO hardcoded literal replaced with _MISO constant.
    Removed stale DISPLAY_DC comment from main.py.
    [main.py, robot_face.py]
2026-03-28 fix(display): rotate ILI9488 output by 180 degrees
    Set MADCTL to the 180-degree landscape orientation so the face UI renders upright for inverted physical mounting.
    [robot_face.py]
2026-03-29 feat(display): highlight out-of-range sensor values in red
    Sensor readings that fall outside plant tolerance thresholds
    now render in red instead of cyan on the status bar.
    [main.py, robot_face.py]
